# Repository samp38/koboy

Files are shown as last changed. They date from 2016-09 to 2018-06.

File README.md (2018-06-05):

# Kobo Mini to Flight Computer Kit

## Description
Turn your kobo mini into a complete flight instrument :-)
This project allows you to build an extension card for Kobo which runs XCSoar. The extension card includes a GPS and a pressure sensor. It acts as a sound variometer while it sends data (GPS NMEA data, Vz, temperature, absolute pressure) to XCSoar. In this repo you will find:
- Eagle files and guide to realize the electronic card
- Firmware source (and precompiled hex binaries) for the mcu
- STL parts for the Kobo Mini to receive electronic card (and a bigger battery for long flights)
- XCSoar software for Kobo

### How it works
The GPS chip is standalone. As long as it's powered, it runs and sends NMEA data through its TX output at a given (user definable) frequency. The microntroller manages the pressure sensing and computing: pressure is measured, numerically filtered and derivated at 50Hz to provide Vz. To work with the GPS chip, the microcontroller detects the beginning of the PA6H TX communication and waits the time needed to send variometer data between GPS data bursts. It can seem dubious but it works very well for years in my case. The variometer data sent by the microcontroller to XCSoar mimics a Digifly Leonardo. So you just have to select Digifly Leonardo in XCSoar to have the variometer data read and understood by XCSoar. All the steps of the XCSoar configuration is described in the __software__ part.

### Two versions for two interaction options
To control the sound vario volume and turn the extension card on/off (indeed, you might want to use your Kobo as a reader), there are two possibilities and thus two versions of the PCB:
- "button version": meaningful. Short press to loop in sound levels and long press to turn off.
- "tap-tap version": the button is replaced with a accelerometer which detects the tap. Single tap to loop in sound levels and double tap to turn on/off.

## Hardware

The extension card is based on a [PIC24F16KA101](http://ww1.microchip.com/downloads/en/DeviceDoc/39927c.pdf) microcontroller, a GPS patch antenna chip [(PA6H)](https://cdn-shop.adafruit.com/datasheets/GlobalTop-FGPMMOPA6H-Datasheet-V0A.pdf) and a high resolution pressure sensor [(MS5611)](https://infusionsystems.com/support/MS5611-01BA03.pdf).

## Firmware

Compiled with Microchip XC16 compiler

## Software

XCSoar

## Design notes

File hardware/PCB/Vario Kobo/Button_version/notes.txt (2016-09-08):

code commande Farnell
	poussoir 12.5mm		1217772
	poussoir 9.5mm		1217776

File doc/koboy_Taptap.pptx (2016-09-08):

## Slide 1

Koboy v1.0

Koboy Board
Pickit2
Kobo

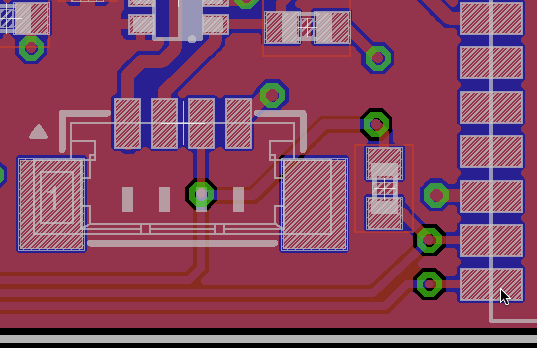
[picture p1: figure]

BATT

GND

EN

TX

VCC

BATT

RX

GND

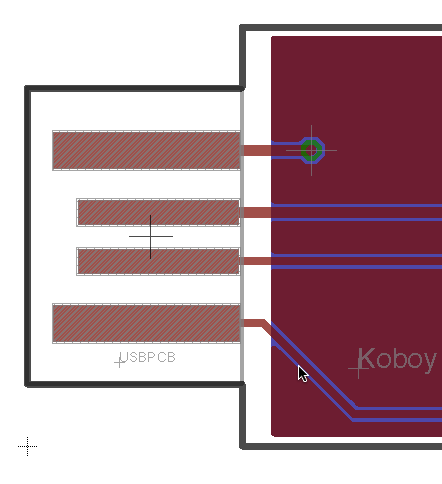
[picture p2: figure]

3

GND

MCLR

PGC

PGD

1

5

4

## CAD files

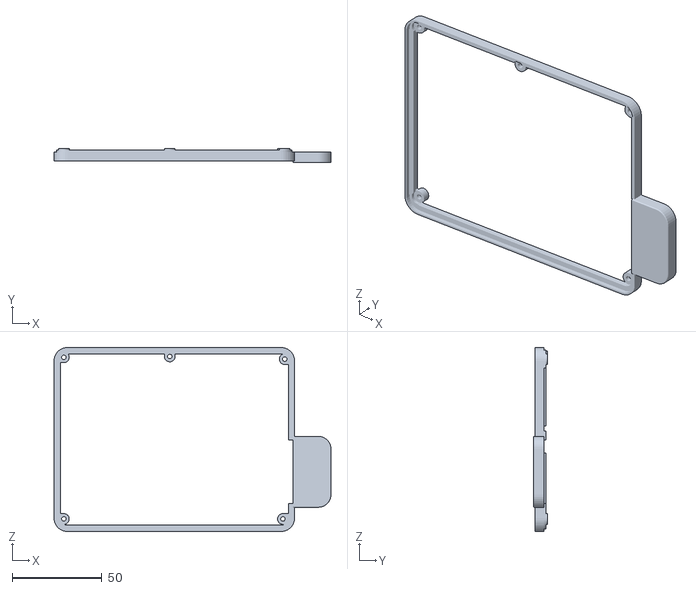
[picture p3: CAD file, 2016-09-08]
hardware/CASE/GPS STANDALONE/Spacer.stl
154.3 x 8.00 x 102.5

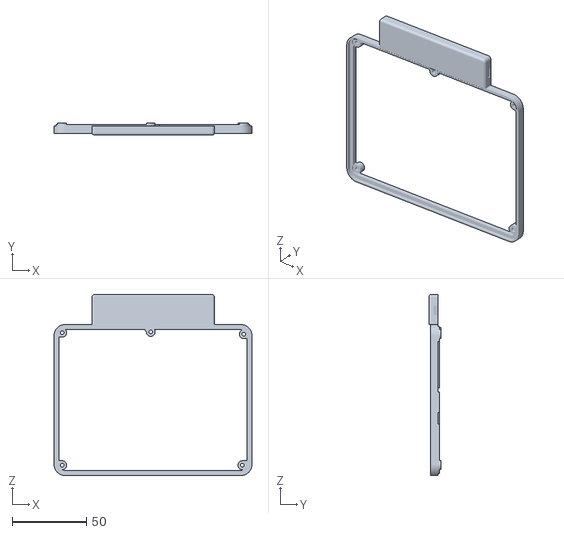
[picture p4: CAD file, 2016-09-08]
hardware/CASE/GPS VARIO/SIDE/button_version/parts/spacerSide.stl
133.0 x 8.00 x 121.7

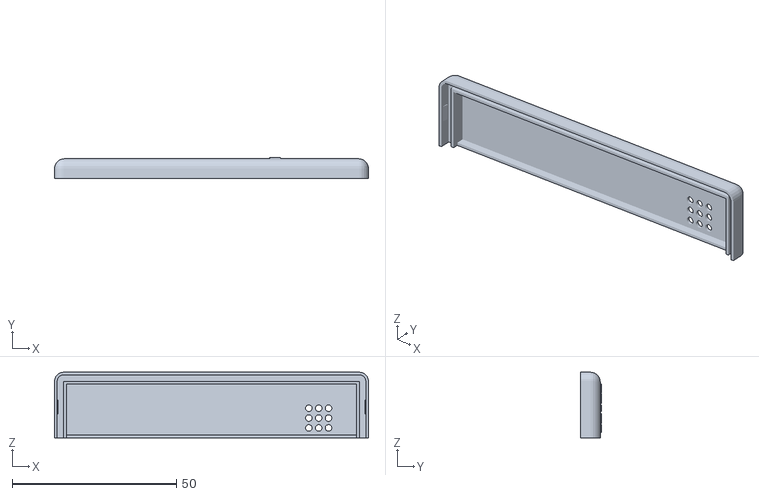
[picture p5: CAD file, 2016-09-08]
hardware/CASE/GPS VARIO/SIDE/taptap_version/parts/cap1.0.stl
95.6 x 6.33 x 20.0

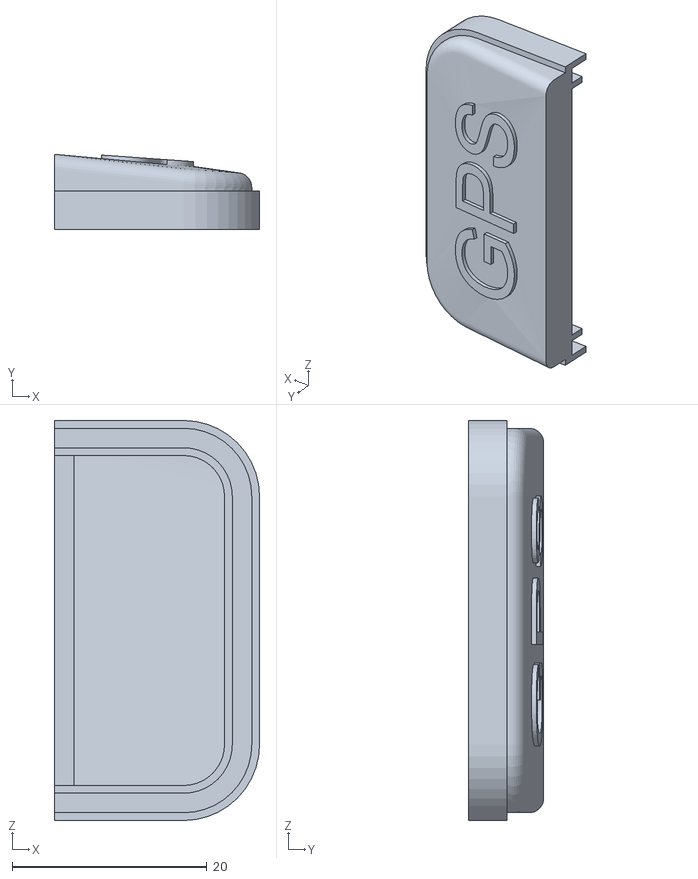
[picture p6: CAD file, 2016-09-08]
hardware/CASE/GPS STANDALONE/Cover.stl
21.1 x 7.75 x 41.1

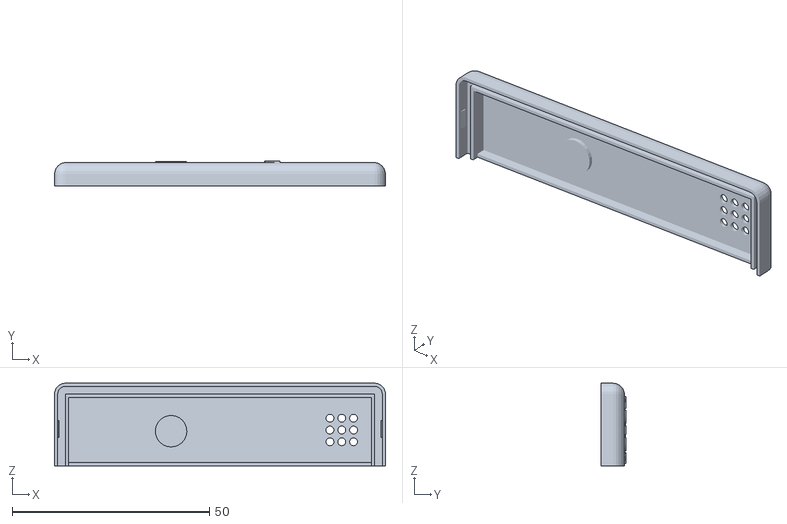
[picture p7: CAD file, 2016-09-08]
hardware/CASE/GPS VARIO/SIDE/button_version/parts/coverSide.stl
84.0 x 6.38 x 21.0

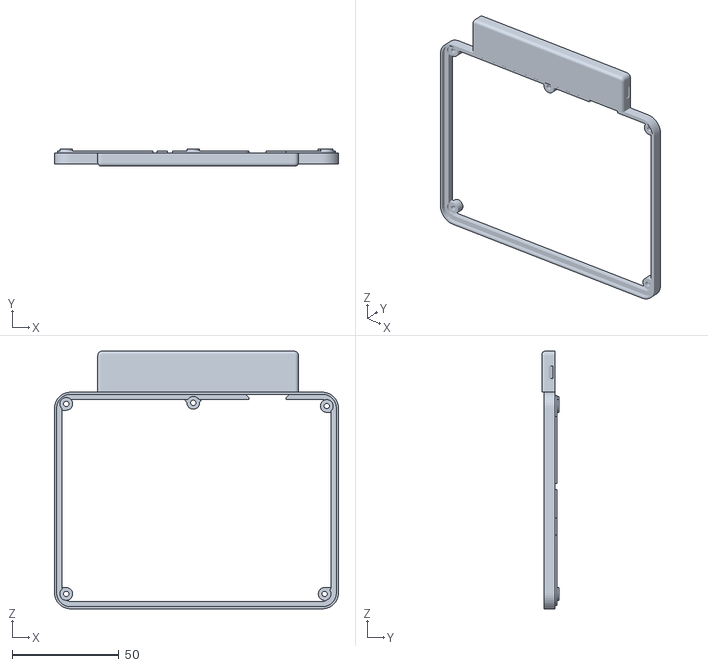
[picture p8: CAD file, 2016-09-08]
hardware/CASE/GPS VARIO/SIDE/taptap_version/parts/spacer1.0.stl
133.0 x 8.00 x 120.7

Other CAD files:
hardware/CASE/GPS STANDALONE/Spacer.skp
hardware/CASE/GPS VARIO/SIDE/button_version/assembly.skp
hardware/CASE/GPS VARIO/SIDE/taptap_version/assembly.skp

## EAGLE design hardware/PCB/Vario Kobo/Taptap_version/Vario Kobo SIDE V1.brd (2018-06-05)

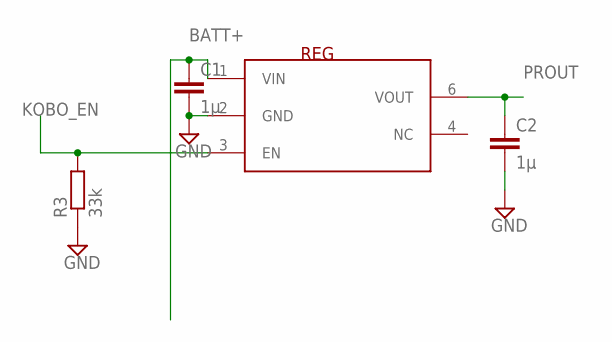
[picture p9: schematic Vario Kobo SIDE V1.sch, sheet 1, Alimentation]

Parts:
C1, C2: 1µ; C0603
R3: 33k; R0603
REG: ADP160/161/162/163; TSOT23-6_DDC

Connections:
BATT+: C1.1, REG.1 (VIN); also elsewhere on the board
GND: C1.2, C2.2, R3.1, REG.2 (GND); also elsewhere on the board
KOBO_EN: R3.2, REG.3 (EN); also elsewhere on the board
PROUT: C2.1, REG.6 (VOUT); also elsewhere on the board

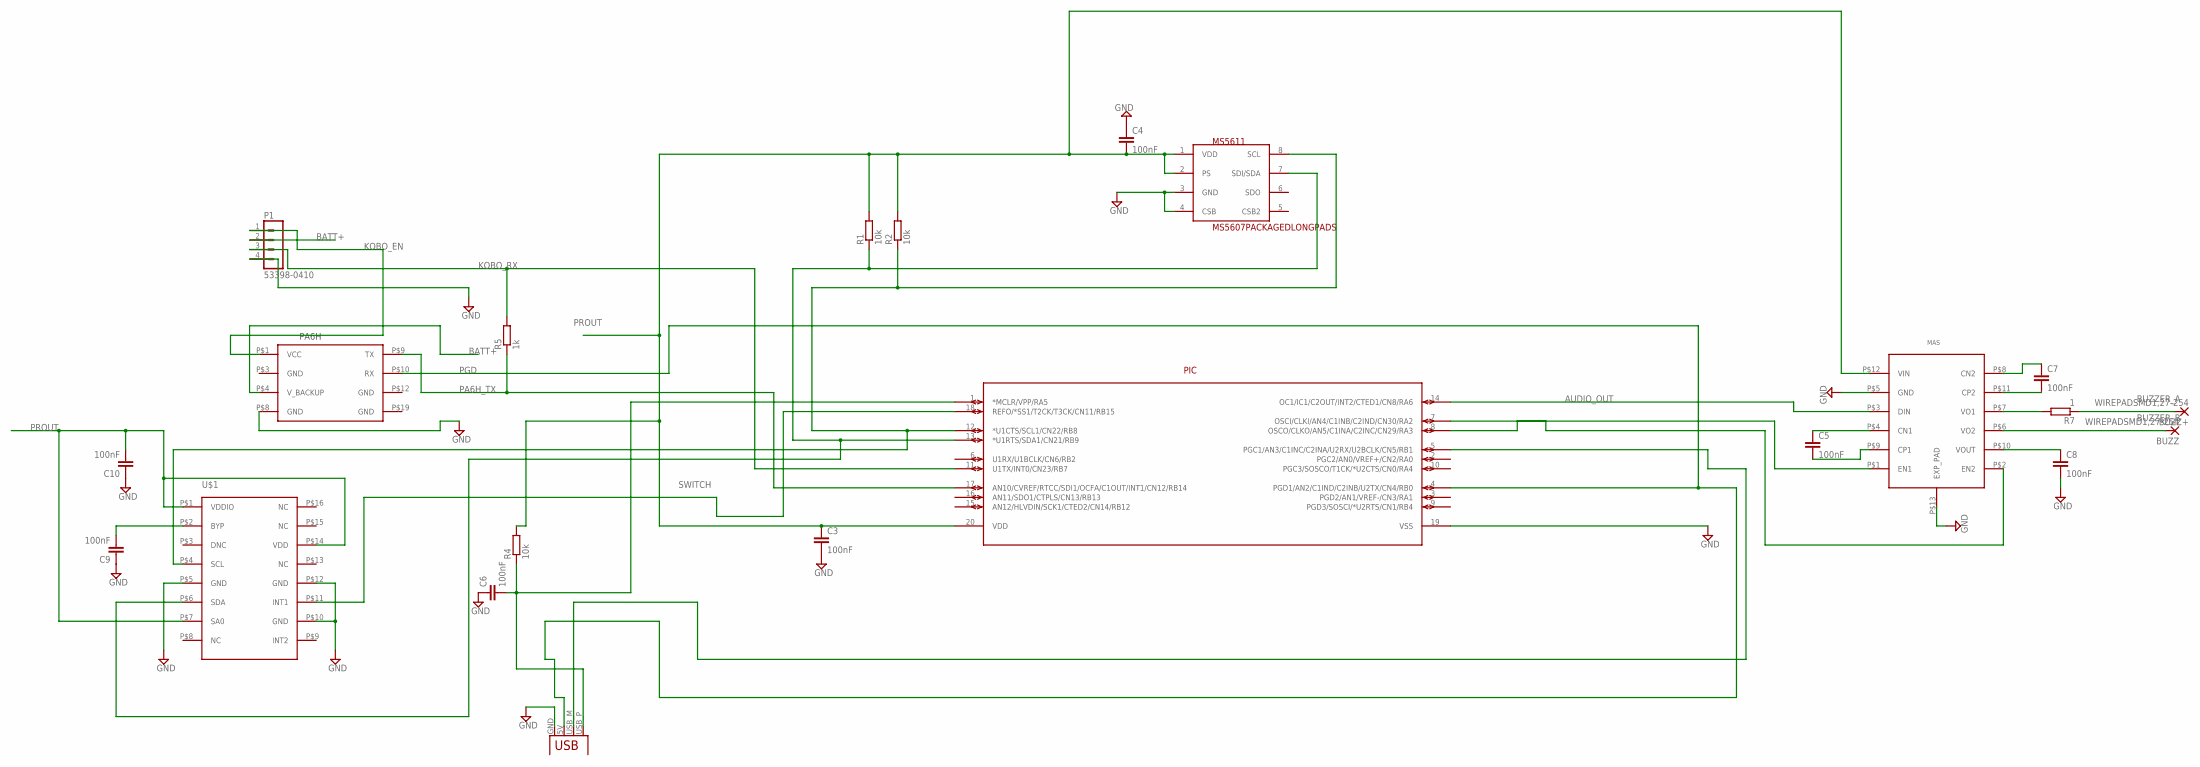
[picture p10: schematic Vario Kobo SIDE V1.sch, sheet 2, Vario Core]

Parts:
BUZZ: WIREPADSMD1,27-254; SMD1,27-2,54
BUZZ+: WIREPADSMD1,27-254; SMD1,27-2,54
C3, C4, C5, C6, C7, C8, C9, C10: 100nF; C0603
MAS: MAS6240; QFN12_3X3_LONGPADS
MS5611: MS5607PACKAGEDLONGPADS; MS5607-02BA03_LONGPADS
P1: 53398-0410
PA6H: PA6H; PA6H_PRINT
PIC: PIC24F16KA101-X_; SSOP20_MC
R1, R2, R4: 10k; R0603
R5: 1k; R0603
R7: 1; R0603
U$1: MMA8452LONGPADS; MMA845X_LONG_PADS
X1: USBPCB; USB-A-PCB

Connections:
AUDIO_OUT: MAS.P$3 (DIN), PIC.14 (OC1/IC1/C2OUT/INT2/CTED1/CN8/RA6)
BATT+: P1.2, PA6H.P$4 (V_BACKUP); also elsewhere on the board
BUZZER_A: BUZZ+.1, R7.1
BUZZER_B: BUZZ.1, MAS.P$6 (VO2)
GND: C3.2, C4.1, C6.1, C8.2, C9.1, C10.1, MAS.P$5 (GND), MAS.P$13 (EXP_PAD), MS5611.3 (GND), MS5611.4 (CSB), P1.4, PA6H.P$8 (GND), PIC.19 (VSS), U$1.P$5 (GND), U$1.P$10 (GND), U$1.P$12 (GND), X1.GND; also elsewhere on the board
KOBO_EN: P1.1, PA6H.P$1 (VCC); also elsewhere on the board
KOBO_RX: P1.3, PIC.11 (U1TX/INT0/CN23/RB7), R5.2
MCLR: C6.2, PIC.1 (*MCLR/VPP/RA5), R4.1, X1.USB_P (D+)
unnamed: C8.1, MAS.P$10 (VOUT)
unnamed: C5.1, MAS.P$4 (CN1)
unnamed: C5.2, MAS.P$9 (CP1)
unnamed: C7.2, MAS.P$11 (CP2)
unnamed: C7.1, MAS.P$8 (CN2)
unnamed: MAS.P$7 (VO1), R7.2
unnamed: MAS.P$1 (EN1), PIC.8 (OSCO/CLKO/AN5/C1INA/C2INC/CN29/RA3)
unnamed: C9.2, U$1.P$2 (BYP)
unnamed: MAS.P$2 (EN2), PIC.7 (OSCI/CLKI/AN4/C1INB/C2IND/CN30/RA2)
PA6H_TX: PA6H.P$9 (TX), PIC.17 (AN10/CVREF/RTCC/SDI1/OCFA/C1OUT/INT1/CN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), R5.1
PGC: PIC.5 (PGC1/AN3/C1INC/C2INA/U2RX/U2BCLK/CN5/RB1), X1.USB_M (D-)
PGD: PA6H.P$10 (RX), PIC.4 (PGD1/AN2/C1IND/C2INB/U2TX/CN4/RB0), X1.5V (VBUS)
PROUT: C3.1, C4.2, C10.2, MAS.P$12 (VIN), MS5611.1 (VDD), MS5611.2 (PS), PIC.20 (VDD), R1.2, R2.2, R4.2, U$1.P$1 (VDDIO), U$1.P$7 (SA0), U$1.P$14 (VDD); also elsewhere on the board
SCL: MS5611.8 (SCL), PIC.12 (*U1CTS/SCL1/CN22/RB8), R2.1, U$1.P$4 (SCL)
SDA: MS5611.7 (SDI/SDA), PIC.13 (*U1RTS/SDA1/CN21/RB9), R1.1, U$1.P$6 (SDA)
SWITCH: PIC.18 (REFO/*SS1/T2CK/T3CK/CN11/RB15), U$1.P$11 (INT1)

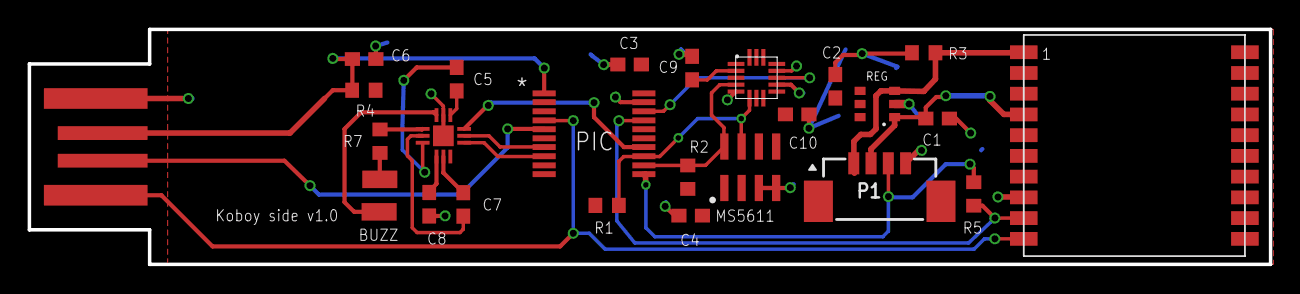
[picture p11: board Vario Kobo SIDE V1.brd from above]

Board: 2 copper layers, 89.8 x 17.0 mm, 26 parts (0 on the bottom side), 24 nets.

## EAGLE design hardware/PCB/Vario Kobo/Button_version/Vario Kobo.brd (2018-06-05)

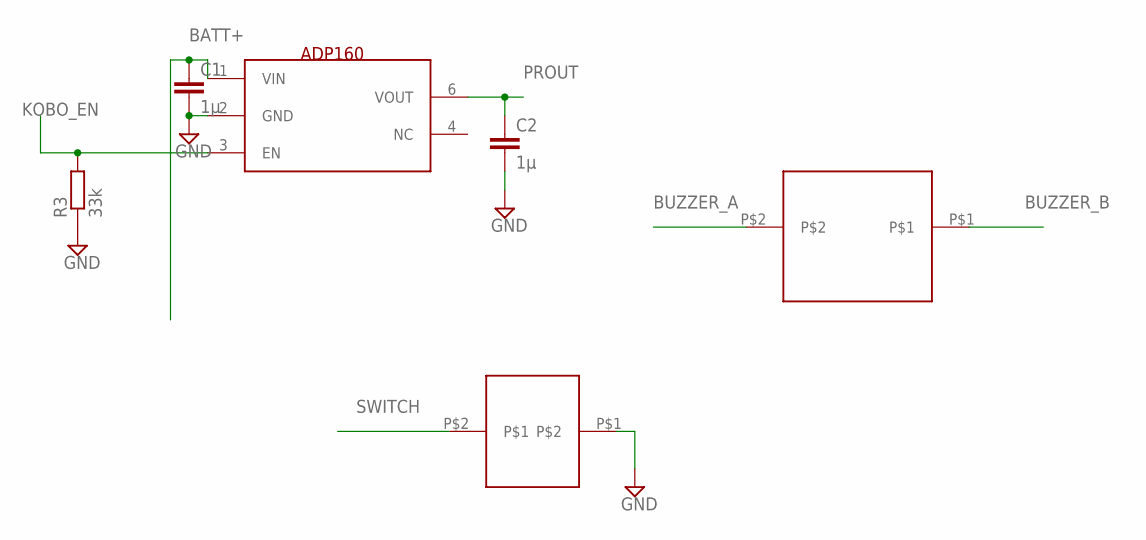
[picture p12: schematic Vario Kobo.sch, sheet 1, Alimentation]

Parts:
ADP160: ADP160/161/162/163; TSOT23-6_DDC
BUTTON: SMS_J_LEAD
BUZZER: PKLCS1212E2000-R1; PKLCS1212E2000-R1-SMD
C1, C2: 1µ; C0603
R3: 33k; R0603

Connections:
BATT+: ADP160.1 (VIN), C1.1; also elsewhere on the board
BUZZER_A: BUZZER.P$2; also elsewhere on the board
BUZZER_B: BUZZER.P$1; also elsewhere on the board
GND: ADP160.2 (GND), BUTTON.P$1, C1.2, C2.2, R3.1; also elsewhere on the board
KOBO_EN: ADP160.3 (EN), R3.2; also elsewhere on the board
PROUT: ADP160.6 (VOUT), C2.1; also elsewhere on the board
SWITCH: BUTTON.P$2; also elsewhere on the board

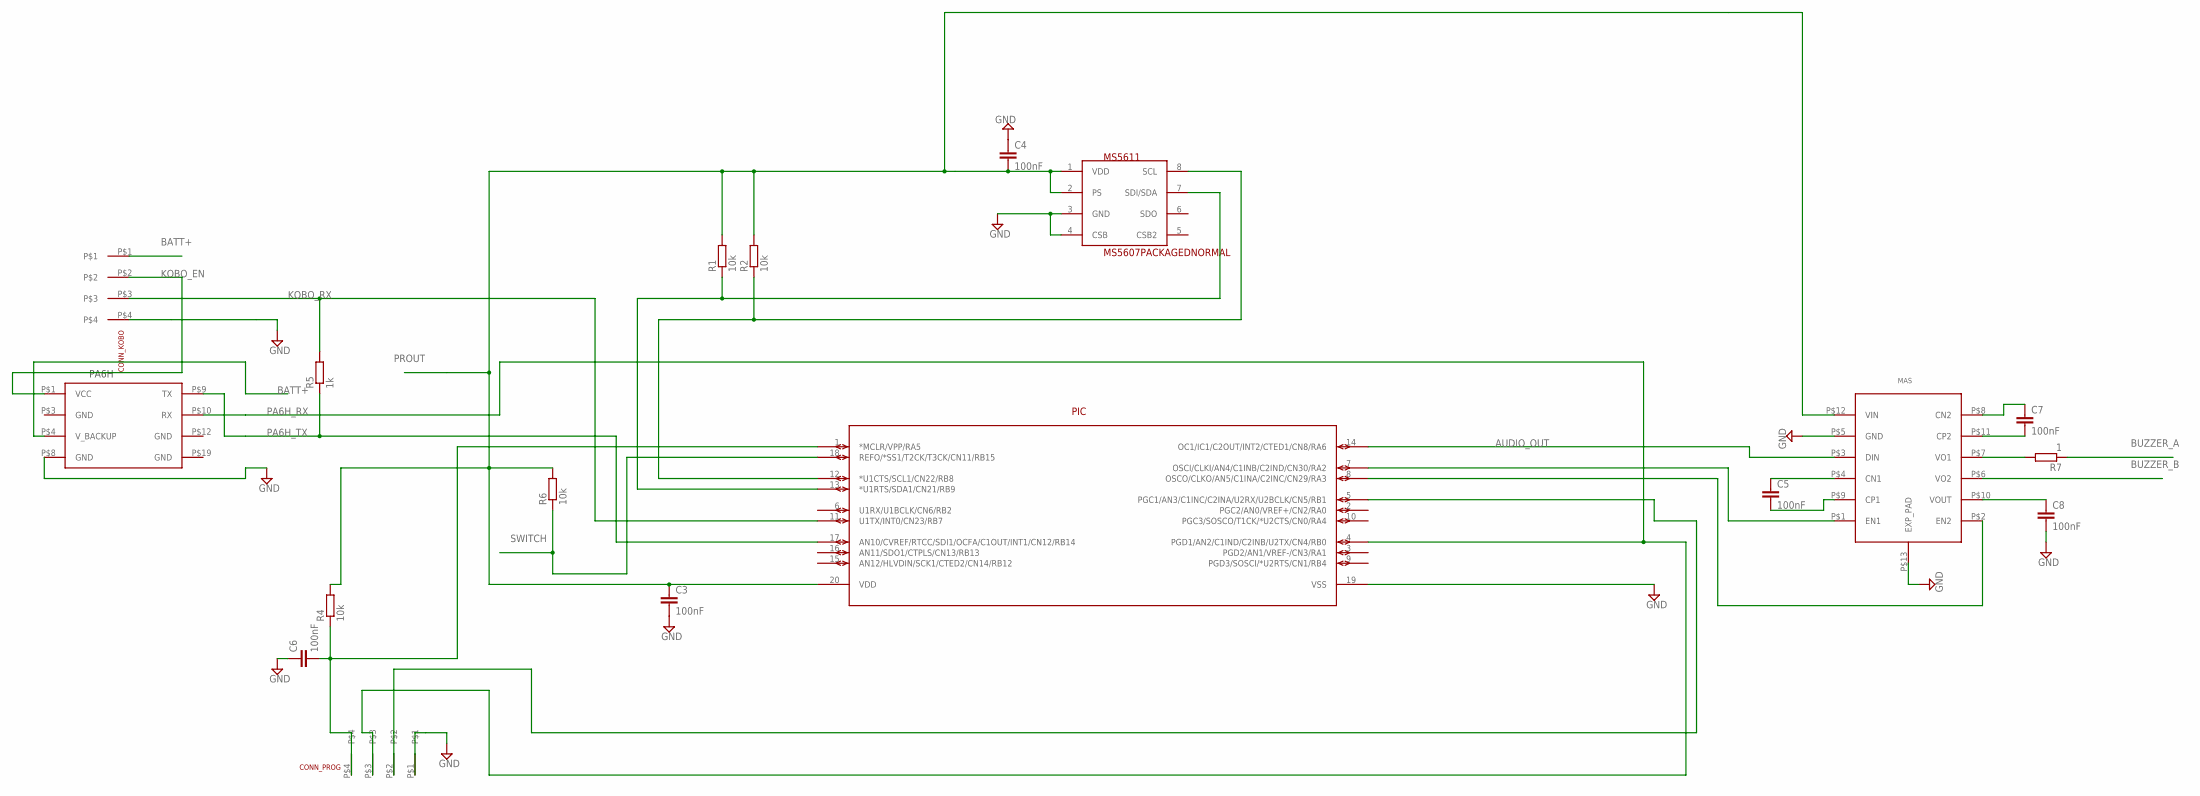
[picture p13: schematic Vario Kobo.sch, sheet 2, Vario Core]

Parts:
C3, C4, C5, C6, C7, C8: 100nF; C0603
CONN_KOBO: PICO-EZMATE4; PICO-EZMATE4-PCB
CONN_PROG: PICO-EZMATE4; PICO-EZMATE4-PCB
MAS: MAS6240; QFN12_3X3_LONGPADS
MS5611: MS5607PACKAGEDNORMAL; MS5607-02BA03
PA6H: PA6H; PA6H_PRINT
PIC: PIC24F16KA101-X_; SSOP20_MC
R1, R2, R4, R6: 10k; R0603
R5: 1k; R0603
R7: 1; R0603

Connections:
AUDIO_OUT: MAS.P$3 (DIN), PIC.14 (OC1/IC1/C2OUT/INT2/CTED1/CN8/RA6)
BATT+: CONN_KOBO.P$1, PA6H.P$4 (V_BACKUP); also elsewhere on the board
BUZZER_A: R7.1; also elsewhere on the board
BUZZER_B: MAS.P$6 (VO2); also elsewhere on the board
GND: C3.2, C4.1, C6.1, C8.2, CONN_KOBO.P$4, CONN_PROG.P$1, MAS.P$5 (GND), MAS.P$13 (EXP_PAD), MS5611.3 (GND), MS5611.4 (CSB), PA6H.P$8 (GND), PIC.19 (VSS); also elsewhere on the board
KOBO_EN: CONN_KOBO.P$2, PA6H.P$1 (VCC); also elsewhere on the board
KOBO_RX: CONN_KOBO.P$3, PIC.11 (U1TX/INT0/CN23/RB7), R5.2
MCLR: C6.2, CONN_PROG.P$4, PIC.1 (*MCLR/VPP/RA5), R4.1
unnamed: C8.1, MAS.P$10 (VOUT)
unnamed: C5.1, MAS.P$4 (CN1)
unnamed: C5.2, MAS.P$9 (CP1)
unnamed: C7.2, MAS.P$11 (CP2)
unnamed: C7.1, MAS.P$8 (CN2)
unnamed: MAS.P$7 (VO1), R7.2
unnamed: MAS.P$1 (EN1), PIC.7 (OSCI/CLKI/AN4/C1INB/C2IND/CN30/RA2)
unnamed: MAS.P$2 (EN2), PIC.8 (OSCO/CLKO/AN5/C1INA/C2INC/CN29/RA3)
PA6H_RX: CONN_PROG.P$3, PA6H.P$10 (RX), PIC.4 (PGD1/AN2/C1IND/C2INB/U2TX/CN4/RB0)
PA6H_TX: PA6H.P$9 (TX), PIC.17 (AN10/CVREF/RTCC/SDI1/OCFA/C1OUT/INT1/CN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), R5.1
PGC: CONN_PROG.P$2, PIC.5 (PGC1/AN3/C1INC/C2INA/U2RX/U2BCLK/CN5/RB1)
PROUT: C3.1, C4.2, MAS.P$12 (VIN), MS5611.1 (VDD), MS5611.2 (PS), PIC.20 (VDD), R1.2, R2.2, R4.2, R6.2; also elsewhere on the board
SCL: MS5611.8 (SCL), PIC.12 (*U1CTS/SCL1/CN22/RB8), R2.1
SDA: MS5611.7 (SDI/SDA), PIC.13 (*U1RTS/SDA1/CN21/RB9), R1.1
SWITCH: PIC.18 (REFO/*SS1/T2CK/T3CK/CN11/RB15), R6.1; also elsewhere on the board

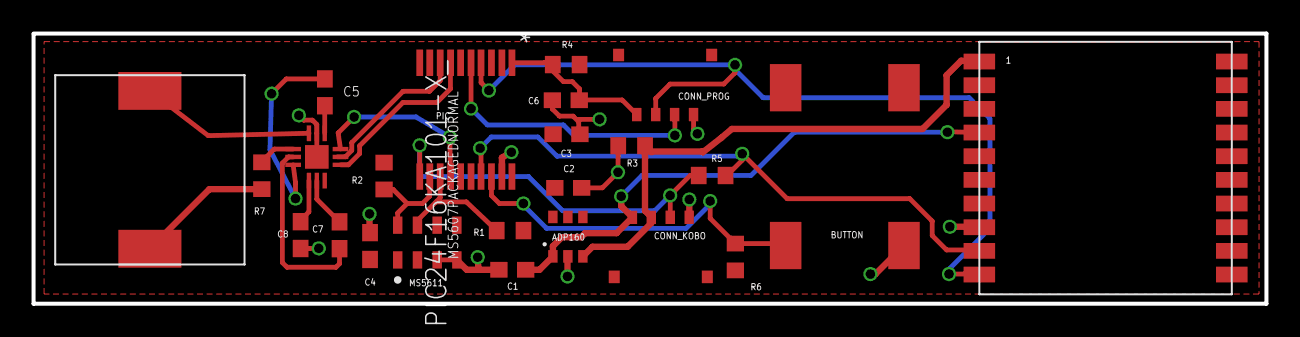
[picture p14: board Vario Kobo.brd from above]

Board: 2 copper layers, 78.1 x 17.1 mm, 24 parts (0 on the bottom side), 23 nets.

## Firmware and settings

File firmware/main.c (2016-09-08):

#include "pic24_all.h"
#include "pcb_version.h"
#include "i2c.h"
#include "timers.h"
#include "sensor.h"
#include "audio.h"
#include "filters.h"
#include "vario.h"
#include "button.h"
#include <stdio.h>
#include "uart.h"
#include "chars.h"
#if PCB_VERSION == 1
#include "MMA8452.h"
#endif

#define GPS_2Hz
#define DEBUG
//#define ELLE_AIME_LA_BITE

#ifdef DEBUG
    char dbgBuf[50];
#endif

// Transmit buffer to Kobo
char koboTxBuf[82];
char *txBufPtr;

u8 timer1Cnt = 0;
const u8 ctimer1Max_kobo = 3;

#define NBVALUES 10
s32 values[NBVALUES];
u8 values_i = 0;

// mutexes for variable protection
u8 mutex_8bits = 0;
// bit 0: NEW DATA available for NMEA sentence
// bit 1: Begin of time window for data sending

#define MUTEX_NEW_DATA_BIT     0
#define MUTEX_TIMETOSEND_BIT   1
#define MUTEX_TRANSMITTING_BIT 2

// bufferized variables
s16 varioBuf;
s8 temperatureBuf;
u32 pressureBuf;

_FBS( BSS_OFF & BWRP_OFF )
_FGS( GSS0_OFF & GWRP_OFF )
_FOSCSEL( FNOSC_FRCDIV  & IESO_OFF )
_FOSC( FCKSM_CSECMD & POSCFREQ_100KHZ & OSCIOFNC_ON & POSCMOD_NONE)
_FWDT( FWDTEN_OFF & WINDIS_OFF & FWPSA_PR128 & WDTPS_PS32768 )
_FPOR( MCLRE_ON & BORV_1_8V & AI2C1SEL_PRI & PWRTEN_OFF & BOREN_BOR3)
_FICD( BKBUG_OFF & COE_OFF & ICS_PGx3 )
_FDS( DSWDTEN_OFF & DSBOR_OFF & RTCCREF_OFF & DSWDTLPRC_OFF & DSWDTPS_DSWDTPS_0 )


volatile u8 tmr1_waiting = 0;
u8 sns_status = 0;
u32 Praw = 0;

#define INTRO_LENGTH 7
u32 intro_freqs[INTRO_LENGTH] = {440, 0,  698, 0,  659, 0,  587};
u32 intro_times[INTRO_LENGTH] = {600, 40, 600, 40, 600, 40, 1200};


void startElapsedTime(void) {
    tmr1_Start(100000);
    _T1IE = 0;
}

void setMutexBit (u8 *mutex, const u8 bitnb) {
    // protect critical section
    asm("DISI #55"); // disable interrupts for the next 55 instruction cycles (intendedly too much)
    *mutex = (*mutex)|(1 << bitnb);
	asm("DISI #0"); // re-enable interrupts immediately
}

void resetMutexBit (u8 *mutex, const u8 bitnb) {
    // protect critical section
    asm("DISI #55"); // disable interrupts for the next 55 instruction cycles (intendedly too much)
    *mutex = (*mutex) & (~(1 << bitnb));
	asm("DISI #0"); // re-enable interrupts immediately
}

u8 getMutexBit (u8 mutex, const u8 bitnb) {
    return (mutex & (1 << bitnb)) >> bitnb;
}

void printElapsedTime(void) {
    sprintf(dbgBuf, "Elapsed Time = %u ms\r\n", TMR1);
    tmr1_Stop();
    uart_Print(dbgBuf);
    sns_status = 0;
    sns_TriggerTemperatureSample();
    tmr1_Start(MEASURE_PERIOD_T);
}

void mcu_Init(void) {
    AD1PCFG = 0xFFFF;            // set all analog-input enabled pins (ANx) to digital mode
    CLKDIVbits.RCDIV = 3;  	 // FRC oscillator 8MHz divided by 8
    CONFIG_RA6_AS_DIG_OUTPUT();  // 14 : Audio output
    // Uart Trigger for transmission timing (pin 17, INT1)
    CONFIG_RB14_AS_DIG_INPUT();

    // Outputs for volume control
    CONFIG_RA3_AS_DIG_OUTPUT();
    CONFIG_RA2_AS_DIG_OUTPUT();


    _DSSR = 0;      // clear RELEASE bit
    _INT0IE = 0;    // only enabled when entering deep sleep mode
    _INT0 = 0;      // Clear Deep Sleep on INT0 edge flag
    _INT1IE = 0;    // only enabled after vario initialisation
    _INT1EP = 0;
    _INT1IP = 1;

    
    uart2_Config();
    uart1_Config();

    i2c_Config();
    tmr1_Config();
    tmr2_Config();
    tmr3_Config();

    button_Config();
    audio_Config();
#if PCB_VERSION == 1
    MMA8452_Init();
#endif
}

void INT1_callback(void) {
    //_INT1IE = 0; not needed
    timer1Cnt = 0;
}

void __attribute__((interrupt, no_auto_psv)) _INT1Interrupt(void){
    _INT1IF = 0;
    INT1_callback();
}

void U1TX_callback(void){
    //check if the whole buffer has been sent (i.e.: character = '\0')
    if(*txBufPtr) {
        U1TXREG = *(txBufPtr++);   // transfer data byte to TX reg
    }
    else {
        // disable interrupt
        IEC0bits.U1TXIE = 0;
        // disable UART
        U1STAbits.UTXEN = 0;
        resetMutexBit (&mutex_8bits, MUTEX_TRANSMITTING_BIT);
        //_INT1IE = 1; not needed
    }
}

void tmr1_callback(void) {
    tmr1_Stop();
    u32 filtrdP = 0;

    if (tmr1_waiting) {
        tmr1_waiting = 0;
    } else {
        ClrWdt();
        _IDLE = 0;
        if (sns_status) {
            ///////////////////////////////////
            sns_ReadADC(&Praw);
            sns_TriggerTemperatureSample();
            /////////////////////////////////// 2ms
            tmr1_Start(MEASURE_PERIOD_T);
        } else {
            u32 Traw;
            s16 temperature;
            sns_ReadADC(&Traw);
            sns_TriggerPressureSample();
            tmr1_Start(MEASURE_PERIOD_P);
            temperature = sns_CompensateTemperature(Traw);            
            timer1Cnt = timer1Cnt + 1;
            s32 Press = sns_CompensatePressure(Praw);
            filtrdP = filterPressure(Press);
//            sprintf(dbgBuf, "Pressure : %ld\r\n", filtrdP);
//            uart_Print(dbgBuf);
            if (filtrdP != (s32)(0xFFFFFFFF)){
                vario_ping(filtrdP);
            }
            if ( (getMutexBit (mutex_8bits, MUTEX_NEW_DATA_BIT) == 0 )) { //if main() is ready to send another NMEA sentence, give it some values
                varioBuf = vario_get_speed();
                temperatureBuf = temperature;
                pressureBuf = filtrdP;
                setMutexBit (&mutex_8bits, MUTEX_NEW_DATA_BIT); // main() will see it when it has some free time
            }
            if (timer1Cnt == ctimer1Max_kobo) { //if this is the right time to send an NMEA sentence, tell it to main() through the mutex
                setMutexBit (&mutex_8bits, MUTEX_TIMETOSEND_BIT);                
            }
            else { // else, set the mutex to zero so main() will wait for the right time
                resetMutexBit (&mutex_8bits, MUTEX_TIMETOSEND_BIT);
            }
        }
        sns_status = !sns_status;        
    }
}

void tmr1_wait(u32 ms) {
    tmr1_Stop();
    tmr1_waiting = 1;
    tmr1_Start(10 * ms);
    while (tmr1_waiting){
        Nop();
    }
}

int main(void) {
    int i = 0;
    u8 checksum;

    mcu_Init();
    ClrWdt();
    sns_Reset();
    tmr1_wait(2000);
    audio_Beep(0);
    sns_Config();
    sns_status = 0;
    
#ifdef ELLE_AIME_LA_BITE
    u8 intro_i;
    for (intro_i = 0; intro_i < INTRO_LENGTH; intro_i++) {
        audio_Beep(intro_freqs[intro_i]);
        wait(intro_times[intro_i]);
    }
    audio_Beep(0);
#else
    audio_Beep(220);
    tmr1_wait(80);
    audio_Beep(1100);
    tmr1_wait(80);
    audio_Beep(2200);
    tmr1_wait(80);
    audio_Beep(0);
#endif
    tmr1_wait(500);
    // 2Hz GPS NMEA Update rate
#ifdef GPS_2Hz
    tmr1_wait(500);
    sprintf(dbgBuf, "$PMTK220,500*2B\r\n");
    uart_Print(dbgBuf);
    tmr1_wait(500);
#else
    sprintf(dbgBuf, "$PMTK220,1000*1F\r\n");
    uart_Print(dbgBuf);
    wait(500);
#endif
    // format NMEA string with dummy characters instead of numbers
    sprintf (koboTxBuf, "$D,VVVV,PPPPPP,,,TTTT,,,,*AA\r\n");
 
    sns_TriggerTemperatureSample();
    tmr1_Start(MEASURE_PERIOD_T);
    vario_init();
    _INT1IE = 1;
    Nop();
	
	// low priority (non realtime) actions are put in the following loop. It will
	// be interrupted all the time...
    while(1){
        if ((getMutexBit (mutex_8bits, MUTEX_NEW_DATA_BIT) == 1)) { //a new data is ready to be sent
            // fill NMEA string
            // "to_chars" functions return 1 (error) if number is not codable on the requested
            // number of digits. For instance this will be the case if pressure is out of bounds
            // (0xFFFFFFFF). In that case no serial frame will be sent to the Kobo!
            if (  (s16_to_chars_decimal (koboTxBuf + 3, 4, varioBuf)
                + u32_to_chars_decimal (koboTxBuf + 8, 6, pressureBuf)
                + s8_to_chars_decimal  (koboTxBuf + 17, 4, temperatureBuf) ) == 0 ) { //if no error on number conversions

                // compute checksum and add it to NMEA string
                i = 1;
                checksum = 0;
                while (koboTxBuf [i] != '*') {
                    checksum ^= koboTxBuf [i++];
                }
                i++;
                u8_to_chars_hexadecimal (koboTxBuf + i, checksum);

                // Set transmit buffer pointer to the first character to be sent
                txBufPtr = koboTxBuf;

                // wait until it is the right time to send the NMEA sentence
                while ((getMutexBit (mutex_8bits, MUTEX_TIMETOSEND_BIT) == 0)) {
                    Nop();
                }

                IEC0bits.U1TXIE = 1;
                U1STAbits.UTXEN = 1;

                // indicate start of transmission (will be reset by the U1TX interrupt routine when msg is fully sent)
                setMutexBit (&mutex_8bits, MUTEX_TRANSMITTING_BIT);

                U1TX_callback ();

                // wait until frame is fully sent
                while ((getMutexBit (mutex_8bits, MUTEX_TRANSMITTING_BIT) == 1)) {
                    Nop();
                }
            }
        }
		// reset mutex so that vario loop can update values with fresh ones
        resetMutexBit (&mutex_8bits, MUTEX_NEW_DATA_BIT);
    }

    return 0;
}

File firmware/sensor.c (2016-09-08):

#include "pic24_all.h"
#include "i2c.h"

#define I2C_ID_MS5611    ((u8)0b11101110)
#define I2C_ID_MS5611_RST ((u8) 0x1E)
u8 I2C_ID_MS5607_C[7] = {0, 0b10100010, 0b10100100, 0b10100110, 0b10101000, 0b10101010, 0b10101100 };
#define I2C_ID_MS5611_CONVERT_PRESSURE_4096 ((u8)0x48)
#define I2C_ID_MS5611_CONVERT_TEMP_4096     ((u8)0x52)
#define I2C_ID_MS5611_READ_ADC              ((u8)0x00)

// MS5611 calibration coefficients
u16 COEFS[7];

s32 dT = 68;
// D2 typical value : 8077736
s16 sns_CompensateTemperature(u32 D2)	{
    // Difference between actual and reference temperature
    dT = D2 - ((u32)COEFS[5] << 8); // dT easily goes up to 250000     C5*256 = 8 256 000
    // Actual temperature (-40 unsigned long 85°C with 0.01°C resolution)
    s32 TEMP = 2000 + ((dT * (s64)COEFS[6]) >> 23);
    return (s16) (TEMP/100);
}

s32 sns_CompensatePressure(u32 D1)  {
//    sprintf(dbg, "%lu\t", D1);
//    uart_Print(dbg);
//    sprintf(dbg, "%ld\t", dT);
//    uart_Print(dbg);
    // Offset at actual temperature
    s64 OFF = ((s64)COEFS[2] << 16) + (((s64)COEFS[4] * dT) >> 7);
//    sprintf(dbg, "%lld\t", OFF);
//    uart_Print(dbg);
    
    // Sensitivity at actual temperature
    s64 SENS = ((s64)COEFS[1] << 15) + (((s64)COEFS[3] * dT) >> 8);
//    sprintf(dbg, "%lld\t", SENS);
//    uart_Print(dbg);
    // Temperature compensated pressure (10 to 1200mbar with 0.01mbar resolution)
    s32 P = (((D1 * SENS) >> 21 ) - OFF) >> 15;

    return P;
}

// Trigger a Pressure measurement and conversion
void sns_TriggerPressureSample(void) {
    i2c_Write1(I2C_ID_MS5611,I2C_ID_MS5611_CONVERT_PRESSURE_4096);
}

// Trigger a Temperature measurement and conversion
void sns_TriggerTemperatureSample(void) {
    i2c_Write1(I2C_ID_MS5611,I2C_ID_MS5611_CONVERT_TEMP_4096);
}

// Read the result of the conversion (temperature or pressure)
void sns_ReadADC(u32 * value) {
    u8 temp[3];
    i2c_RcvBuf(I2C_ID_MS5611,I2C_ID_MS5611_READ_ADC,3,temp);

    Nop();
    Nop();
    Nop();
    
    *value = 0X00000000 | temp[0];
    *value = *value << 8 | temp[1];
    *value = *value << 8| temp[2];
}

// Reset the sensor : load the calibration coefficients into the memory
void sns_Reset(void) {
    i2c_Write1(I2C_ID_MS5611, I2C_ID_MS5611_RST);
}

/**
 * call sns_Reset, wait, then call this
 * Read the calibration coefficient for the calculations
 */
void sns_Config(void) {
    u8 b[2];

    int i = 1;
    for (; i <= 6; i++) {
        i2c_RcvBuf(I2C_ID_MS5611, I2C_ID_MS5607_C[i], 2, b);
        COEFS[i] = ((u16) b[0] << 8) | (u16)b[1];
    }
}

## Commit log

2016-09-08 Import files
    [Cover.skp, Cover.stl, Spacer.skp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]
2016-09-08 clean files
    [Vario Kobo SIDE V1.GBL, Vario Kobo SIDE V1.GBO, Vario Kobo SIDE V1.GBP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]
2016-09-09 Clean 3D Files and docs
    Ignoring makefiles
    [Cover.skp, Spacer.skp, assembly.skp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]
2018-06-05 cleaning up
    [Cover.skp, Spacer.skp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]
2026-10-15 Migrate Vario Kobo button version PCB from Eagle to KiCad
    - Add KiCad 10 project imported from the Eagle sch/brd, with fixes
    (MAS6240 shorts, board outline, PA6H GND pins, PROUT tracks,
    GND pour on both layers)
    - Ignore KiCad lock, backup and cache files
    - Add an "Open issues" section to the README
2026-10-15 Restructure Vario Kobo schematic into main + power supply sheets
    - Rename the KiCad project to main (main.kicad_pro/.kicad_sch/.kicad_pcb)
    and drop the empty "Alimentation" top-level sheet left by the Eagle import.
    - Move the ADP160 regulator (R3, C1, C2) into a "Power supply" sub-sheet.
    - Redraw the main sheet on A3 by function (barometer, Kobo connector + GPS,
    programming/MCLR, button, MAS6240 audio) with net labels instead of long
    wires, and add design notes per block.
    - Add no-connect flags and PWR_FLAGs: ERC goes from 20 violations to
    11 warnings (Eagle pin types), no errors.
    - Update the PCB from the schematic (renamed nets, same routing).
    - README: refresh the ERC/DRC open iss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
2026-10-15 Rename references and lay out a readable silkscreen
    - Rename the Eagle-style references to short standard ones:
    PIC0->U1, MS5611->U2, MAS0->U3, ADP160->U4, PA6H0->U5,
    CONN_KOBO0->J1, CONN_PROG0->J2, BUTTON0->SW1, BUZZER0->BZ1.
    - Move every footprint reference field next to its part, 0.8 mm text,
    clear of pads, vias and the board edge, closer to its own part than
    to any other one.
    - Add footprint-owned silkscreen texts: J1/J2 pin names and a "1" next
    to pin 1 of U1-U5, so they follow the parts if they move.
    - Hide value fields; drop the Eagle "1" next to the GPS and move the U1
    "*" mark to F.Fab.
    - README: DRC is down from 74 to 22 warnings (footprint outlines over pads).
    Co-Auth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
2026-10-15 Use Gekkio's FGPMMOPA6H for the GPS and clean up ERC
    - U5 (GPS): replace the Eagle PA6H symbol and footprint with Gekkio's
    FGPMMOPA6H (gekkio-kicad-libs, CC BY 4.0, copied into libs/gekkio/ and
    registered in the project library tables). Same pad geometry; adds the
    datasheet's 1.2 mm NPTH under the module, a courtyard and a silkscreen
    outline clear of the pads. Unused pins flagged no-connect (datasheet:
    leave floating).
    - Fix pin electrical types in the Eagle-imported symbols (connectors and
    switch passive, MAS6240/ADP160 power pins power in/out), add PWR_FLAGs
    on BATT+ and KOBO_EN, drop the now redundant one on PROUT.
    - ERC: 0 errors, 0 warnings. DRC: 2 warnings (buzzer outline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
2026-10-15 Use KiCad's standard 0603 HandSolder footprints for R and C
    Replace the Eagle-imported R0603/C0603 footprints of R1-R7 and C1-C8
    with Resistor_SMD:R_0603_1608Metric_Pad0.98x0.95mm_HandSolder and
    Capacitor_SMD:C_0603_1608Metric_Pad1.08x0.95mm_HandSolder, easier to
    solder by hand. Footprint positions and routing are unchanged; the
    track ends still land inside the new pads.
    Reference fields are put back at their 0.8 mm silkscreen spots and all
    Value fields are hidden on F.Fab (U2's moved off F.Silkscreen too).
    Netlist topology unchanged, ERC 0, DRC 0 errors / 2 warnings (BZ1 outline).
2026-10-16 Migrate the taptap version from Eagle to KiCad
    - Import Vario Kobo SIDE V1 (sch + brd) into a KiCad 10 project
    (main.kicad_pro), structured like the button version: root main
    sheet redrawn on A3 by function with local labels, plus a
    "Power supply" sub-sheet (ADP160, R3, C1, C2)
    - Fix the schematic import: two collinear Eagle wires were merged,
    which put MAS6240 EN1 on PIC pin 7 and left EN2 floating; EN1 is
    now on RA3 (pin 8) and EN2 on RA2 (pin 7), as on the board and in
    firmware/audio.c
    - Board: design rules imported from the button version, track
    widths narrowed where they missed the 0.2mm clearance, VO1 track
    re-centred on its pad, leftover Eagle stu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
2026-10-16 Replace Eagle GND symbols with KiCad's power:GND
    - Button and taptap versions: all Eagle supply GND symbols (#GNDxx,
    #SUPPLYxx) replaced by power:GND (#PWR01..), with their reference
    hidden like any KiCad power symbol.
    - Netlists unchanged; ERC button 0, taptap unchanged.

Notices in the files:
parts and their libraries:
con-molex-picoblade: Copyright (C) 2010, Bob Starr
